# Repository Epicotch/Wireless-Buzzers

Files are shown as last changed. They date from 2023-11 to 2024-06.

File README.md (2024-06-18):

# Wireless Buzzers

### **NOTE: This thing was fairly slapdash and still has a few bugs. Only use this as a reference, not as a final product.**

3D printed parts: https://cad.onshape.com/documents/be3b52bcdf6f61d23120cde6/w/8980feb9664c58ae24ebe7fa/e/dfef3d1a1d06f241238ca187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

Shield: [][cc-by-nc]

This work is licensed under a
[Creative Commons Attribution-NonCommercial 4.0 International License][cc-by-nc].

[][cc-by-nc]

[cc-by-nc]: https://creativecommons.org/licenses/by-nc/4.0/
[cc-by-nc-image]: https://licensebuttons.net/l/by-nc/4.0/88x31.png
[cc-by-nc-shield]: https://img.shields.io/badge/License-CC%20BY--NC%204.0-lightgrey.svg

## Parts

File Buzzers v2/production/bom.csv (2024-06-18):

Designator | Footprint | Quantity | Value | LCSC Part #
BOOT1, EN1 | SW_PUSH_6mm_H5mm | 2 | SW_SPST
BT1 | BatteryHolder_TruPower_BH-331P_3xAA | 1 | 4.5V
C1 | 1206 | 1 | 10uF
C10 | 1206 | 1 | 0.1u
C2 | CP_EIA-3528-12_Kemet-T | 1 | 10uF
C3 | 1206 | 1 | 22uF/10V
C4 | 1206 | 1 | 0.1uF/50V
C6, C7 | 1206 | 2 | 1n
C8, C9 | 1206 | 2 | 22p
D1 | 1206 | 1 | D
H1, H2, H3, H4 | MountingHole_3.5mm_Pad | 4 | MountingHole_Pad
J1 | JST_XH_B2B-XH-A_1x02_P2.50mm_Vertical | 1 | POWER_SWITCH_CONNECTOR
J2, J3, J4, J5 | Jack_3.5mm_CUI_SJ1-3523N_Horizontal | 4 | AudioJack3
J6 | JST_XH_B4B-XH-A_1x04_P2.50mm_Vertical | 1 | I2C_OLED
J7 | JST_XH_B2B-XH-A_1x02_P2.50mm_Vertical | 1 | MODE_SWITCH_CONNECTOR
J8 | JST_XH_B2B-XH-A_1x02_P2.50mm_Vertical | 1 | BUZZER
J9 | USB_Micro-B_Amphenol_10103594-0001LF_Horizontal | 1 | USB_B_Micro
Q1, Q2 | SOT-23 | 2 | Q_NPN_CBE
R1, R12 | 1206 | 2 | 470
R10, R7, R8, R9 | 1206 | 4 | 165Ω
R13, R14, R15, R16, R2, R3, R4, R5, R6 | 1206 | 9 | 10k
R17, R18 | 1206 | 2 | 1k
U1 | SOT-223-3_TabPin2 | 1 | AMS1117-3.3
U2 | ESP32-WROOM-32 | 1 | ESP32-WROOM-32
U3 | SOIC-16_3.9x9.9mm_P1.27mm | 1 | CH340G
Y1 | Crystal_HC49-U_Vertical | 1 | 12MHz

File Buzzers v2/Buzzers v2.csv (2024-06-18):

Source: | /Users/berniejin/Documents/Buzzers v2/Buzzers v2.kicad_sch
Date: | Thursday, July 20, 2023 at 09:28:40 PM
Tool: | Eeschema (6.0.10-0)
Generator: | /Applications/KiCad/KiCad.app/Contents/SharedSupport/plugins/bom_csv_grouped_by_value_with_fp.py
Component Count: | 32
Ref | Qnty | Value | Cmp name | Footprint | Description | Vendor
BT1, | 1 | 4.5V | Battery | Battery:BatteryHolder_TruPower_BH-331P_3xAA | Multiple-cell battery
C1, | 1 | 10uF | C_Small | Capacitor_SMD:C_1206_3216Metric | Unpolarized capacitor, small symbol
C2, | 1 | 10uF | C_Polarized_Small_US | Capacitor_SMD:CP_Elec_4x3 | Polarized capacitor, small US symbol
C3, | 1 | 22uF/10V | C_Small | Capacitor_SMD:C_1206_3216Metric | Unpolarized capacitor, small symbol
C4, C5, | 2 | 0.1uF/50V | C_Small | Capacitor_SMD:C_1206_3216Metric | Unpolarized capacitor, small symbol
D1, | 1 | LED | LED | LED_SMD:LED_0201_0603Metric | Light emitting diode
H1, H2, H3, H4, | 4 | MountingHole_Pad | MountingHole_Pad | MountingHole:MountingHole_3.5mm_Pad | Mounting Hole with connection
J1, | 1 | POWER_SWITCH_CONNECTOR | Conn_01x02_Male | Connector_JST:JST_XH_B2B-XH-A_1x02_P2.50mm_Vertical | Generic connector, single row, 01x02, script generated (kicad-library-utils/schlib/autogen/connector/)
J2, J3, J4, J5, | 4 | AudioJack3 | AudioJack3 | Connector_Audio:Jack_3.5mm_CUI_SJ1-3523N_Horizontal | Audio Jack, 3 Poles (Stereo / TRS)
J6, | 1 | I2C_OLED | Conn_01x04_Male | Connector_JST:JST_XH_B4B-XH-A_1x04_P2.50mm_Vertical | Generic connector, single row, 01x04, script generated (kicad-library-utils/schlib/autogen/connector/)
J7, | 1 | MODE_SWITCH_CONNECTOR | Conn_01x02_Male | Connector_JST:JST_XH_B2B-XH-A_1x02_P2.50mm_Vertical | Generic connector, single row, 01x02, script generated (kicad-library-utils/schlib/autogen/connector/)
J8, | 1 | BUZZER | Conn_01x02_Male | Connector_JST:JST_XH_B2B-XH-A_1x02_P2.50mm_Vertical | Generic connector, single row, 01x02, script generated (kicad-library-utils/schlib/autogen/connector/)
R1, | 1 | 165 | R | Resistor_SMD:R_1206_3216Metric | Resistor
R2, R3, R4, R5, R6, R11, | 6 | 10K | R | Resistor_SMD:R_1206_3216Metric | Resistor
R7, R8, R9, R10, | 4 | 165Ω | R | Resistor_SMD:R_1206_3216Metric | Resistor
U1, | 1 | AMS1117-3.3 | AMS1117-3.3 | Package_TO_SOT_SMD:SOT-223-3_TabPin2 | 1A Low Dropout regulator, positive, 3.3V fixed output, SOT-223
U2, | 1 | ESP32-WROOM-32 | ESP32-WROOM-32 | RF_Module:ESP32-WROOM-32 | RF Module, ESP32-D0WDQ6 SoC, Wi-Fi 802.11b/g/n, Bluetooth, BLE, 32-bit, 2.7-3.6V, onboard antenna, SMD

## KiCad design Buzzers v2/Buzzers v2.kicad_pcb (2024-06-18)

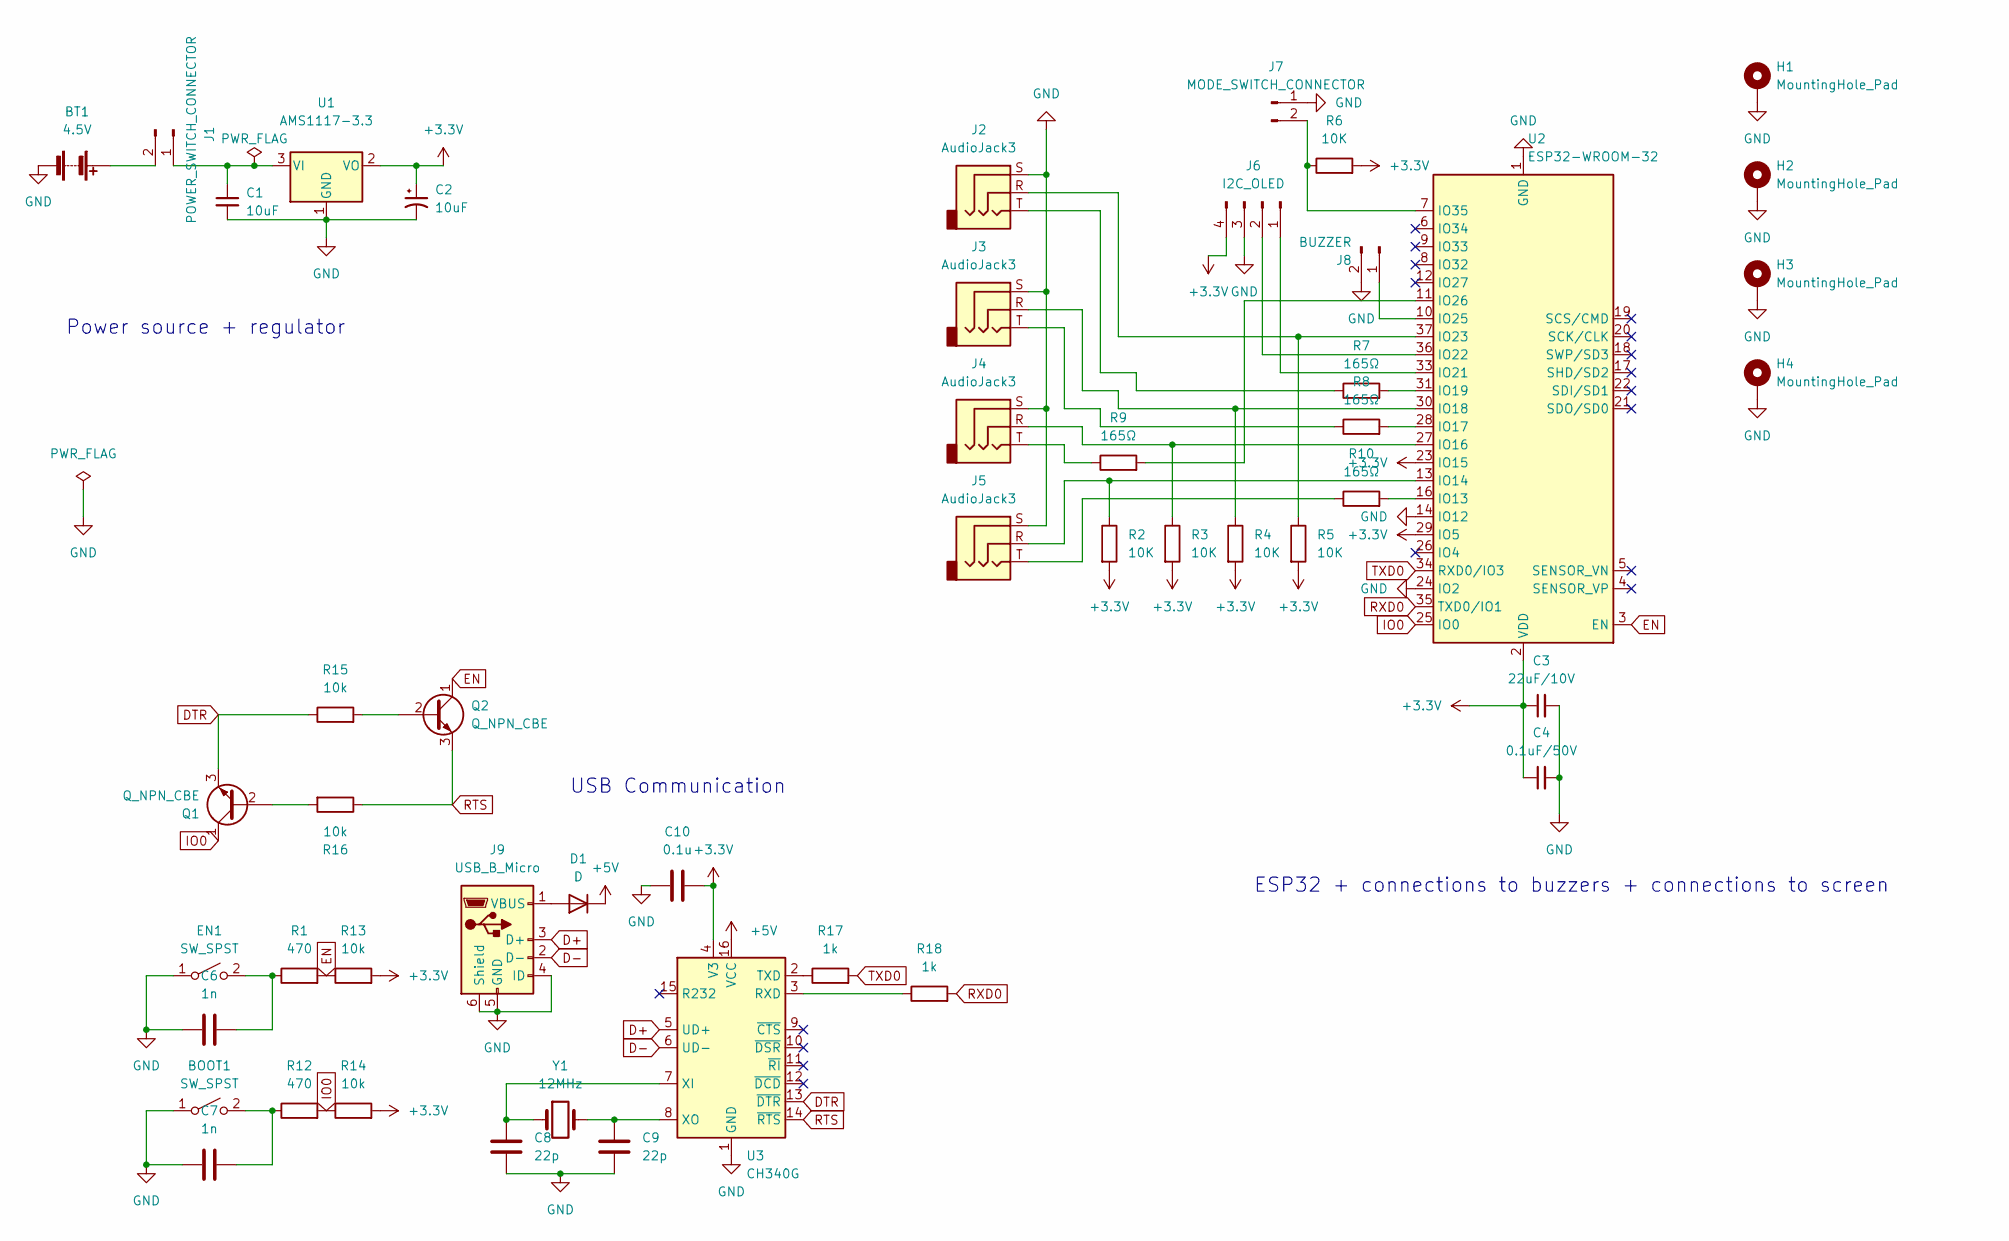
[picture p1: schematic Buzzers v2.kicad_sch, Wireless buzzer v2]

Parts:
BOOT1: SW_SPST; SW_PUSH_6mm_H5mm
BT1: 4.5V; BatteryHolder_TruPower_BH-331P_3xAA
C1: 10uF; C_1206_3216Metric
C2: 10uF; CP_EIA-3528-12_Kemet-T
C3: 22uF/10V; C_1206_3216Metric
C4: 0.1uF/50V; C_1206_3216Metric
C6, C7: 1n; C_1206_3216Metric
C8, C9: 22p; C_1206_3216Metric
C10: 0.1u; C_1206_3216Metric
D1: D; D_1206_3216Metric
EN1: SW_SPST; SW_PUSH_6mm_H5mm
H1, H2, H3, H4: MountingHole_Pad; MountingHole_3.5mm_Pad
J1: POWER_SWITCH_CONNECTOR; JST_XH_B2B-XH-A_1x02_P2.50mm_Vertical
J2, J3, J4, J5: AudioJack3; Jack_3.5mm_CUI_SJ1-3523N_Horizontal
J6: I2C_OLED; JST_XH_B4B-XH-A_1x04_P2.50mm_Vertical
J7: MODE_SWITCH_CONNECTOR; JST_XH_B2B-XH-A_1x02_P2.50mm_Vertical
J8: BUZZER; JST_XH_B2B-XH-A_1x02_P2.50mm_Vertical
J9: USB_B_Micro; USB_Micro-B_Amphenol_10103594-0001LF_Horizontal
Q1, Q2: Q_NPN_CBE; SOT-23
R1, R12: 470; R_1206_3216Metric
R2, R3, R4, R5, R6: 10K; R_1206_3216Metric
R7, R8, R9, R10: 165Ω; R_1206_3216Metric
R13, R14, R15, R16: 10k; R_1206_3216Metric
R17, R18: 1k; R_1206_3216Metric
U1: AMS1117-3.3; SOT-223-3_TabPin2
U2: ESP32-WROOM-32
U3: CH340G; SOIC-16_3.9x9.9mm_P1.27mm
Y1: 12MHz; Crystal_HC49-U_Vertical

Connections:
+3.3V: C2.1, C3.1, C4.1, C10.2, J6.4, R2.2, R3.2, R4.2, R5.2, R6.2, R13.2, R14.2, U1.2 (VO), U2.2 (VDD), U2.23 (IO15), U2.29 (IO5), U3.4 (V3)
+5V: D1.1 (K), U3.16 (VCC)
D+: J9.3 (D+), U3.5 (UD+)
D-: J9.2 (D-), U3.6 (UD-)
DTR: Q1.3 (E), R15.1, U3.13 (~DTR)
EN: Q2.1 (C), R1.2, R13.1, U2.3 (EN)
GND: BOOT1.1 (A), BT1.2 (-), C1.2, C2.2, C3.2, C4.2, C6.1, C7.1, C8.2, C9.2, C10.1, EN1.1 (A), H1.1, H2.1, H3.1, H4.1, J2.S, J3.S, J4.S, J5.S, J6.3, J7.1, J8.2, J9.4 (ID), J9.5 (GND), J9.6 (Shield), U1.1 (GND), U2.1 (GND), U2.14 (IO12), U2.15 (GND), U2.24 (IO2), U2.38 (GND), U2.39 (GND), U3.1 (GND)
IO0: Q1.1 (C), R12.2, R14.1, U2.25 (IO0)
unnamed: BT1.1 (+), J1.2
unnamed: C1.1, J1.1, U1.3 (VI)
unnamed: C6.2, EN1.2 (B), R1.1
unnamed: BOOT1.2 (B), C7.2, R12.1
unnamed: C8.1, U3.7 (XI), Y1.1
unnamed: C9.1, U3.8 (XO), Y1.2
unnamed: D1.2 (A), J9.1 (VBUS)
unnamed: J2.R, R5.1, U2.37 (IO23)
unnamed: J2.T, R7.1
unnamed: J3.R, R4.1, U2.30 (IO18)
unnamed: J3.T, R8.1
unnamed: J4.R, R3.1, U2.27 (IO16)
unnamed: J4.T, R9.1
unnamed: J5.R, R2.1, U2.13 (IO14)
unnamed: J5.T, R10.1
unnamed: J6.1, U2.33 (IO21)
unnamed: J6.2, U2.36 (IO22)
unnamed: J7.2, R6.1, U2.7 (IO35)
unnamed: J8.1, U2.10 (IO25)
unnamed: Q1.2 (B), R16.2
unnamed: Q2.2 (B), R15.2
unnamed: R7.2, U2.31 (IO19)
unnamed: R8.2, U2.28 (IO17)
unnamed: R10.2, U2.16 (IO13)
unnamed: R17.1, U3.2 (TXD)
unnamed: R18.1, U3.3 (RXD)
unnamed: R9.2, U2.11 (IO26)
RTS: Q2.3 (E), R16.1, U3.14 (~RTS)
RXD0: R18.2, U2.35 (TXD0/IO1)
TXD0: R17.2, U2.34 (RXD0/IO3)

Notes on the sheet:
ESP32 + connections to buzzers + connections to screen
USB Communication
Power source + regulator

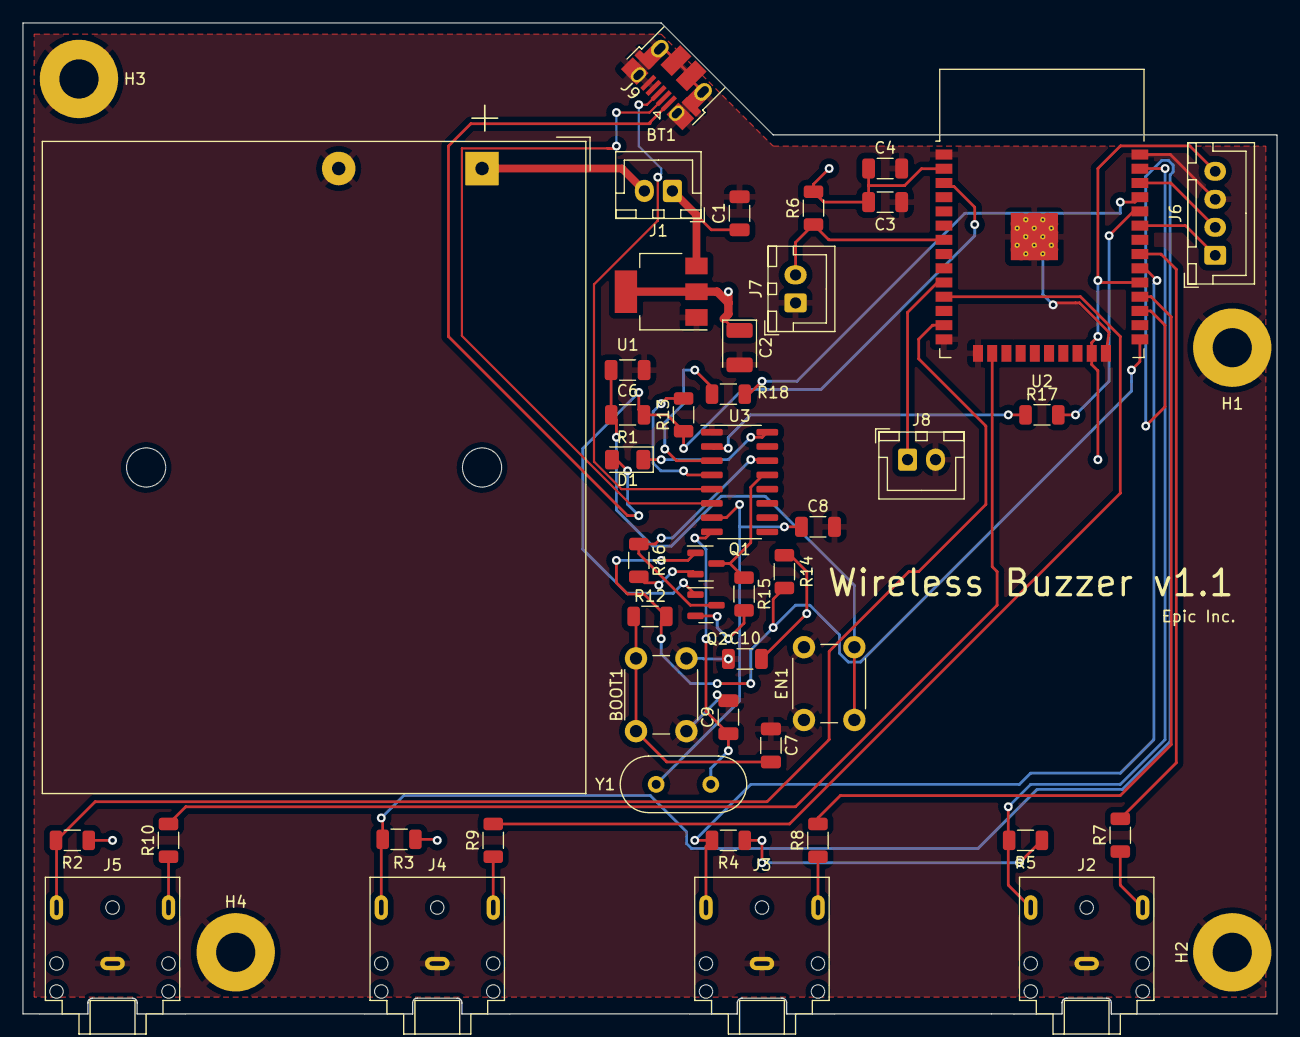
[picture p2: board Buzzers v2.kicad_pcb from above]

Board: 2 copper layers, 112.0 x 88.5 mm, 49 parts (0 on the bottom side), 38 nets.

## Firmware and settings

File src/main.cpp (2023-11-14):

#include <Arduino.h>
#include <esp_now.h>
#include <WiFi.h>
#include <algorithm>
#include <esp_wifi.h>
#include <Wire.h>
#include <SPI.h>
#include <Wire.h>
#include <Adafruit_GFX.h>
#include <Adafruit_SSD1306.h>

const long BUZZ_LENGTH = 1000L;
const long DISCOVERY_TIMEOUT = 600L;

const int MODE_PIN = 35;
const int BUZZER_PIN = 25;
const int BUZZER_IN_1 = 23;
const int BUZZER_LED_1 = 19;
const int BUZZER_IN_2 = 18;
const int BUZZER_LED_2 = 17;
const int BUZZER_IN_3 = 16;
const int BUZZER_LED_3 = 26;
const int BUZZER_IN_4 = 14;
const int BUZZER_LED_4 = 13;

const int bzLEDs[4] = {BUZZER_LED_1, BUZZER_LED_2, BUZZER_LED_3, BUZZER_LED_4};

const int OLED_SDA = 21;
const int OLED_SCL = 22;

const int SCREEN_WIDTH = 128;
const int SCREEN_HEIGHT = 64;

const int OLED_RESET = -1;
Adafruit_SSD1306 display(SCREEN_WIDTH, SCREEN_HEIGHT, &Wire, OLED_RESET);

unsigned long timerStopTime = (long) 0;

uint8_t buzzed = 100;
uint8_t pairing_index = 0;
int found = 0;
bool match = false;
char id_letter;
uint8_t id;
bool resetting = false;

bool console = false;

bool resetPrev = false;

esp_now_peer_info_t buzzerConsole;
uint8_t addresses[6][6] = {{0xff, 0xff, 0xff, 0xff, 0xff, 0xff}, {0x00, 0x00, 0x00, 0x00, 0x00, 0x00}, {0x00, 0x00, 0x00, 0x00, 0x00, 0x00}, {0x00, 0x00, 0x00, 0x00, 0x00, 0x00}, {0x00, 0x00, 0x00, 0x00, 0x00, 0x00}, {0x00, 0x00, 0x00, 0x00, 0x00, 0x00}};
char letters[6] = {'A', 'B', 'C', 'D', 'E', 'F'};
int chan = 4;

typedef struct struct_message {
	uint8_t msgType;
	uint8_t id;
	uint8_t buzzer;
	uint8_t macAddr[6];
} struct_message;

typedef struct struct_pairing {
	uint8_t msgType;
	uint8_t id;
	uint8_t macAddr[6];
	uint8_t channel;
	uint8_t assigned_id;
} struct_pairing;

struct_message responseData;
struct_message buzzData;
struct_pairing pairingData;

enum MessageType {PAIRING, DATA, REDO, CONFIRM,};
MessageType messagetype;
enum PairingStatus {NOT_PAIRED, PAIR_REQUEST, PAIR_REQUESTED, PAIR_PAIRED,};
PairingStatus pairingStatus = NOT_PAIRED;

enum BuzzStates {NOT_BUZZED, BUZZ_PENDING, BUZZ_SUCCESSFUL, BUZZ_HOLDING, RESET,};
BuzzStates buzzState = NOT_BUZZED;

void(* resetFunc) (void) = 0; //declare reset function @ address 0


void addPeer_buzzer(const uint8_t * mac_addr, uint8_t chan) {
	esp_now_peer_info_t peer;
	esp_now_del_peer(mac_addr);
	memset(&peer, 0, sizeof(esp_now_peer_info_t));
	peer.channel = chan;
	peer.encrypt = 0;
	memcpy(peer.peer_addr, mac_addr, sizeof(uint8_t[6]));
	if (esp_now_add_peer(&peer) != ESP_OK) {
		Serial.println("Failed to add peer");
		return;
	}
	memcpy(addresses[0], mac_addr, sizeof(uint8_t[6]));
}

bool addPeer_console(const uint8_t *peer_addr) {
	memset(&buzzerConsole, 0, sizeof(buzzerConsole));
	const esp_now_peer_info_t *peer = &buzzerConsole;
	memcpy(buzzerConsole.peer_addr, peer_addr, 6);
	memcpy(addresses[pairing_index], peer_addr, 6);

	buzzerConsole.channel = chan;
	buzzerConsole.encrypt = 0;

	bool exists = esp_now_is_peer_exist(buzzerConsole.peer_addr);
	if (exists) {
		return true;
	}
	else {
		esp_err_t pairStatus = esp_now_add_peer(peer);
		if (pairStatus == ESP_OK) {
			display.println("Connected " + letters[pairing_index]);
			display.display();
			return true;
		}
		else {
			Serial.println(esp_err_to_name(pairStatus));
			return false;
		}
	}
}

void printMAC(const uint8_t * mac_addr){
	char macStr[18];
	snprintf(macStr, sizeof(macStr), "%02x:%02x:%02x:%02x:%02x:%02x",
           mac_addr[0], mac_addr[1], mac_addr[2], mac_addr[3], mac_addr[4], mac_addr[5]);
	Serial.print(macStr);
}

void consolePairing(const uint8_t * mac_addr, const uint8_t *incomingData, int len) {
	uint8_t type = incomingData[0];
	Serial.println("Recieved ping");
	switch (type) {
		case PAIRING: // pairing confirmed
			Serial.println("Type pairing");
			memcpy(&pairingData, incomingData, sizeof(pairingData));
			Serial.println("ID = " + pairingData.id);
			if (pairingData.id == 100) {
				Serial.print("Sending pairing response to ");
				printMAC(mac_addr);
				Serial.println("\n");
				pairingData.id = 0;
				WiFi.macAddress(pairingData.macAddr);
				pairingData.channel = chan;
				addPeer_console(mac_addr);
				pairingData.assigned_id = ++pairing_index;
				Serial.println(esp_err_to_name(esp_now_send(mac_addr, (uint8_t *) &pairingData, sizeof(pairingData))));
				Serial.print("Current pairing index: ");
				Serial.println(pairing_index);
			}
			break;
		case DATA:
			Serial.println("huh");
			break;
	}
}

void buzzerPairing(const uint8_t * mac_addr, const uint8_t *incomingData, int len) {
	uint8_t type = incomingData[0];
	Serial.println("Recieved response");
	switch (type) {
		case PAIRING:
			Serial.println("Type pairing");
			memcpy(&pairingData, incomingData, sizeof(pairingData));
			if (pairingData.id == 0) {
				Serial.println("ID 0");
				id_letter = letters[pairingData.assigned_id - 1];
				id = pairingData.assigned_id;
				chan = pairingData.channel;
				addPeer_buzzer(mac_addr, pairingData.channel);
				pairingStatus = PAIR_PAIRED;
				Serial.print("Assigned");
				Serial.println(id_letter);
			}
			break;
		case DATA:
			Serial.println("huh");
			break;
	}
}

void onBuzzResponse(const uint8_t * mac_addr, const uint8_t *incomingData, int len) {
	uint8_t type = incomingData[0];
	Serial.println("Buzzer ping");
	switch (type) {
		case DATA:
			break;
		case REDO:
			Serial.println("Type reset");
			memcpy(&responseData, incomingData, sizeof(incomingData));
			if (responseData.id == 0) {
				Serial.println("From console");
				buzzState = RESET;
			}
			break;
		case CONFIRM:
			Serial.println("Type confirm");
			Serial.println(responseData.buzzer);
			memcpy(&responseData, incomingData, sizeof(incomingData));
			if (responseData.id == 0) {
				Serial.println("Successful buzz");
				timerStopTime = millis() + BUZZ_LENGTH;
				buzzState = BUZZ_SUCCESSFUL;
			}
			break;
		case PAIRING:
			Serial.println("hm");
			break;
	}
}

void onBuzz(const uint8_t * mac_addr, const uint8_t *incomingData, int len) {
	uint8_t type = incomingData[0];
	Serial.println("Recieved onBuzz ping");
	if (buzzState == RESET) 
		return;
	switch (type) {
		case DATA:
			memcpy(&responseData, incomingData, sizeof(incomingData));
			Serial.println("Data!");
			match = false;
			for (int i = 0; i < 4; i++) {
				found = 0;
				for (int j = 0; j < 6; j++) {
					Serial.printf("Comparing %02x to %02x\n", mac_addr[j], addresses[i][j]);
					if (mac_addr[j] == addresses[i][j]) {
						found++;
					}
					if (buzzState == RESET) {
						break;
					}
				}
				if (buzzState == RESET) {
					break;
				}
				if (found == 6) {
					match = true;
					break;
				}
				Serial.print("Matched ");
				Serial.println(found);
			}
			if (buzzState == RESET) {
				break;
			}
			if (!match) {
				Serial.println("No match");
				break;
			}
			Serial.println("MAC address match");
			if (responseData.id != 0) {
				Serial.println("From buzzer!");
				if (buzzState == NOT_BUZZED && digitalRead(BUZZER_IN_1)) {
					Serial.println("Good buzz");
					display.setCursor(44, 18);
					display.setTextSize(5);
					display.setTextColor(WHITE);
					Serial.print(letters[responseData.id - 1]);
					Serial.println(responseData.buzzer + 1);
					display.print(letters[responseData.id - 1]);
					display.print(responseData.buzzer + 1);
					display.display();
					buzzed = responseData.id;
					buzzData.id = 0;
					buzzData.msgType = CONFIRM;
					buzzData.buzzer = responseData.buzzer;
					WiFi.macAddress(buzzData.macAddr);
					Serial.println(esp_err_to_name(esp_now_send(mac_addr, (uint8_t *) &buzzData, sizeof(buzzData))));
					buzzState = BUZZ_SUCCESSFUL;
					}
				else {
					buzzData.id = 0;
					buzzData.msgType = REDO;
					buzzData.buzzer = responseData.buzzer;
					esp_now_send(mac_addr, (uint8_t *) &buzzData, sizeof(buzzData));
				}
			}
			break;
		case PAIRING:
			break;
	}
}

void buzzStateMachine_buzzer() {
	switch (buzzState) {
		case NOT_BUZZED:
			break;
		case BUZZ_PENDING:
			buzzData.buzzer = buzzed;
			buzzData.msgType = DATA;
			WiFi.macAddress(buzzData.macAddr);
			Serial.printf("This MAC: %02x:%02x:%02x:%02x:%02x:%02x\n", buzzData.macAddr[0], buzzData.macAddr[1], buzzData.macAddr[2], buzzData.macAddr[3], buzzData.macAddr[4], buzzData.macAddr[5]);
			buzzData.id = id;
			Serial.print("Buzz on ");
			Serial.print(letters[id - 1]);
			Serial.println(buzzData.buzzer + 1);
			Serial.println(esp_err_to_name(esp_now_send(addresses[0], (uint8_t *) &buzzData, sizeof(buzzData))));
			buzzState = NOT_BUZZED;
			break;
		case BUZZ_SUCCESSFUL:
			digitalWrite(BUZZER_PIN, 1);
			digitalWrite(bzLEDs[buzzed], 1);
			if (millis() > timerStopTime) {
				buzzState = BUZZ_HOLDING;
			}
			break;
		case BUZZ_HOLDING:
			digitalWrite(BUZZER_PIN, 0);
			break;
		case RESET:
			Serial.println("Resetting!");
			digitalWrite(BUZZER_PIN, 0);
			digitalWrite(BUZZER_LED_1, 0);
			digitalWrite(BUZZER_LED_2, 0);
			digitalWrite(BUZZER_LED_3, 0);
			digitalWrite(BUZZER_LED_4, 0);
			buzzed = 100;
			buzzState = NOT_BUZZED;
			break;
	}
}

void buzzStateMachine_console() {
	switch (buzzState) {
		case NOT_BUZZED:
			break;
		case BUZZ_PENDING:
			break;
		case BUZZ_SUCCESSFUL:
			break;
		case BUZZ_HOLDING:
			break;
		case RESET:
			if (resetting) break;
			Serial.println("Resetting");
			buzzed = 100;
			buzzData.id = 0;
			buzzData.msgType = REDO;
			buzzData.buzzer = 100;
			resetting = true;
			for (int i; i < pairing_index; i++) {
				Serial.print("Resetting buzzer ");
				Serial.print(i + 1);
				Serial.print(" at ");
				Serial.printf("%02x:%02x:%02x:%02x:%02x:%02x\n", addresses[i][0], addresses[i][1], addresses[i][2], addresses[i][3], addresses[i][4], addresses[i][5]);
				noInterrupts();
				Serial.println(esp_err_to_name(esp_now_send(addresses[i], (uint8_t *) &buzzData, sizeof(buzzData))));
				interrupts();
			}
			resetting = false;
			buzzState = NOT_BUZZED;
			display.clearDisplay();
			display.display();
			break;
	}
}

void setup() {
	Serial.begin(115200);
	if (!display.begin(SSD1306_SWITCHCAPVCC, 0x3C)) {
		Serial.println("Failed to start OLED");
		for(;;);
	}
	display.setTextColor(WHITE);
	display.clearDisplay();
	display.setTextSize(2);
	display.setCursor(0, 5);
	display.display();
	pinMode(MODE_PIN, INPUT);
	pinMode(BUZZER_PIN, OUTPUT);
	pinMode(BUZZER_IN_1, INPUT);
	pinMode(BUZZER_LED_1, OUTPUT);
	pinMode(BUZZER_IN_2, INPUT);
	pinMode(BUZZER_LED_2, OUTPUT);
	pinMode(BUZZER_IN_3, INPUT);
	pinMode(BUZZER_LED_3, OUTPUT);
	pinMode(BUZZER_IN_4, INPUT);
	pinMode(BUZZER_LED_4, OUTPUT);
	console = !digitalRead(MODE_PIN);

	WiFi.mode(WIFI_STA);
	if (esp_now_init() != ESP_OK) {
		Serial.println("Error initializing ESP-NOW");
		display.setTextSize(3);
		display.println("ESP-NOW failed!");
		display.display();
		return;
	}
	Serial.println(esp_err_to_name(esp_wifi_set_channel(chan, WIFI_SECOND_CHAN_NONE)));
	display.clearDisplay();
	if (console) {
		//display.setCursor(5, 5);
		//display.setTextSize(3);
		Serial.println("Console mode");
		display.println("Console\nmode");
		display.display();
		Serial.println(esp_err_to_name(esp_now_register_recv_cb(consolePairing)));
		while (digitalRead(BUZZER_IN_1) && !(pairing_index == 6)) {}
		Serial.println("Starting game cycle");
		Serial.println(esp_err_to_name(esp_now_unregister_recv_cb()));
		Serial.println(esp_err_to_name(esp_now_register_recv_cb(onBuzz)));
		display.setTextSize(5);
		display.clearDisplay();
	}
	else {
		Serial.println("Buzzer mode");
		display.println("Buzzer\nmode");
		id = 100;
		display.display();
		Serial.println(esp_err_to_name(esp_now_register_recv_cb(buzzerPairing)));
		addPeer_buzzer(addresses[0], chan);
		pairingData.msgType = PAIRING;
		pairingData.id = id;
		pairingData.channel = chan;
		Serial.println(esp_err_to_name(esp_now_send(addresses[0], (uint8_t *) &pairingData, sizeof(pairingData))));
		timerStopTime = DISCOVERY_TIMEOUT + millis();
		pairingStatus = PAIR_REQUESTED;
		while (pairingStatus != PAIR_PAIRED) {
			if (millis() > timerStopTime) {
				// could not find anything
				Serial.println("Unable to find console, retrying...");
				resetFunc();
			}
		}
		Serial.println("Found console!");
		display.println("Connected!");
		display.display();
		Serial.println(esp_err_to_name(esp_now_unregister_recv_cb()));
		Serial.println(esp_err_to_name(esp_now_register_recv_cb(onBuzzResponse)));
		display.setTextSize(5);
		display.clearDisplay();
		display.setCursor(54, 18);
		display.print(letters[id - 1]);
	}
	display.display();
	buzzState = NOT_BUZZED;
}

void loop() {
	//Serial.println("loop weeeeeeeee");
	if (!console) {
		buzzStateMachine_buzzer();
		if (buzzed == 100) {
			if (!digitalRead(BUZZER_IN_1)) {
				buzzed = 0;
			}
			else if (!digitalRead(BUZZER_IN_2)) {
				buzzed = 1;
			}
			else if (!digitalRead(BUZZER_IN_3)) {
				buzzed = 2;
			} 
			else if (!digitalRead(BUZZER_IN_4)) {
				buzzed = 3;
			}
			if (buzzed != 100) {
				buzzState = BUZZ_PENDING;
			}
			Serial.print(!digitalRead(BUZZER_IN_1));
			Serial.print(!digitalRead(BUZZER_IN_2));
			Serial.print(!digitalRead(BUZZER_IN_3));
			Serial.println(!digitalRead(BUZZER_IN_4));
			Serial.print("Current buzz: ");
			Serial.println(buzzed);
		}
	}
	if (console) {
		// do the console logic in here
		buzzStateMachine_console();
		if (!digitalRead(BUZZER_IN_1) && resetPrev) {
			buzzState = RESET;
		}
		resetPrev = digitalRead(BUZZER_IN_1);
	}
}

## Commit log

2023-06-28 Added buzzer discovery logic
    [main.cpp]
2023-06-28 Added buzzing logic on the buzzer side
    [main.cpp]
2023-09-02 Added 6 buzzer functionaliy
    [main.cpp]
2023-11-14 Fixed crashing when trying to reset and buzz at the same time
    [main.cpp]
2024-06-18 PCB Upload stuff
    aaaaa this is a mess
    [Buzzers v2-B_Cu.gbr, Buzzers v2-B_Mask.gbr, Buzzers v2-B_Paste.gbr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]

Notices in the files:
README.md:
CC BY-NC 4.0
